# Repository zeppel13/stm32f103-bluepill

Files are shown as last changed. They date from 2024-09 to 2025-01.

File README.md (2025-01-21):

I designed a working simple STM32 devboard to learn how to use KiCad and design my own PCBs

MCU is a genuine STM32F103C8T6. I'll upload an STM32CubeIDE project soon, planning to also put an libopenCM3 project here. For the programming you'll need a standard ST-LINK programmer (A fake one might be working just fine). The PCB exposes a programming interface with SWD, CLK, +3V3 and GND and BOOT0 with Breakers. 

For the programming

    st-flash write firmware.bin 0x08000000 
    
works fine for me

### Goals of the Project
✅ **Learn to use KiCAD**  
✅ Complete all necessary steps to manufacture the board and proceed with prototypes  
✅ Create a Blue Pill-compatible board with a genuine STM32F103 (no clones like GD32, PY32, etc.)  
✅ Provide a base for future MCU PCB design  
✅ Ensure the PCB fits on a breadboard  
✅ Pay special attention to the routing of high-frequency signals: proper differential pairs for USB, a good ground plane, and always low-impedance return paths  
✅ Make it work  

---

### Non-Goals
- Using the newest or best features. STM32F103 might seem a bit outdated compared to newer STM32 offerings. A brand-name Micro USB-B connector will be used — no USB-C.  
- Power optimization (e.g., removing LEDs, using a more efficient voltage supply, or selecting a low-power MCU).  
- Price optimization. The plan is to build a small batch, not large quantities.  

---

### Errata
- The **BOOTP** header in the silkscreen should be **BOOT0**. I confused the technical jargon of Cortex boot modes with DHCP/BOOTP and didn’t realize the mistake until after producing the samples.  
- The SMD switch for BOOT0 was replaced with a pinout that can be configured with jumpers (HI/LOW).  

top
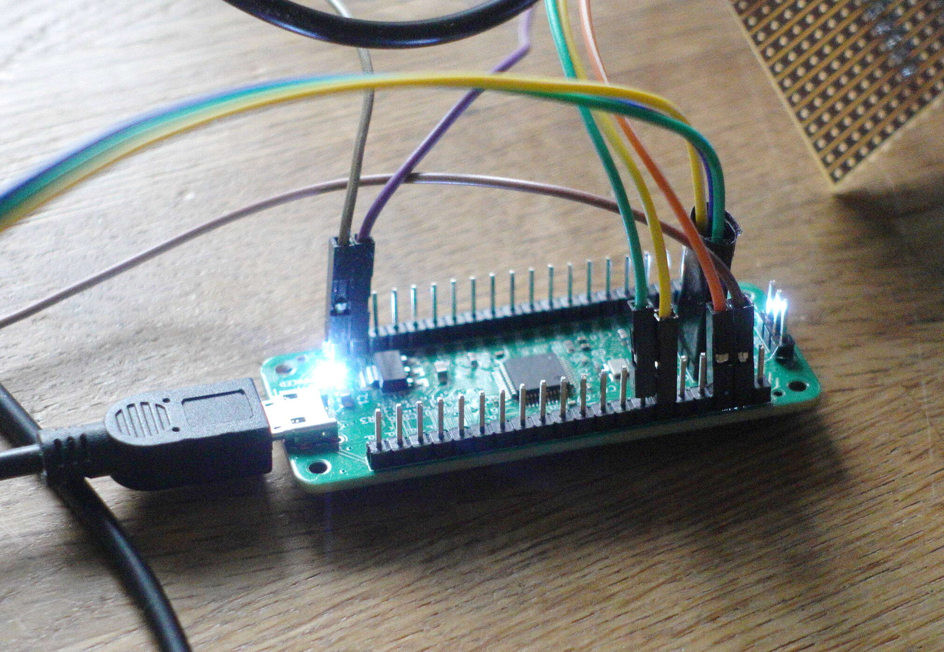
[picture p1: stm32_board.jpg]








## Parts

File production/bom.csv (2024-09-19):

Designator | Footprint | Quantity | Value | LCSC Part #
C1, C2 | 0805 | 2 | 22u
C10, C9 | 0402 | 2 | 1u
C11, C3 | 0603 | 2 | 10u
C12, C13 | 0402 | 2 | 10p
C4, C5, C6, C7 | 0402 | 4 | 100n
C8 | 0402 | 1 | 10n
D1, D2 | 0603 | 2 | RED
FB1 | 0603 | 1 | 120R
H1, H2, H3, H4 | MountingHole_2.2mm_M2 | 4 | MountingHole
J1 | PinHeader_1x04_P2.54mm_Vertical | 1 | Conn_01x04_Male
J2 | USB_Micro-B_Wuerth_629105150521 | 1 | USB_B_Micro
J3 | PinHeader_1x20_P2.54mm_Vertical | 1 | Pinout 1
J4 | PinHeader_1x20_P2.54mm_Vertical | 1 | Pinout 2
R1, R3, R4 | 0402 | 3 | 1k5
R2 | 0402 | 1 | 10k
SW1 | PinHeader_1x03_P2.54mm_Vertical | 1 | Conn_01x03_Male
U1 | SOT-223-3_TabPin2 | 1 | AMS1117-3.3
U2 | LQFP-48_7x7mm_P0.5mm | 1 | STM32F103C8T6
Y1 | Crystal_SMD_3225-4Pin_3.2x2.5mm | 1 | 16MHz

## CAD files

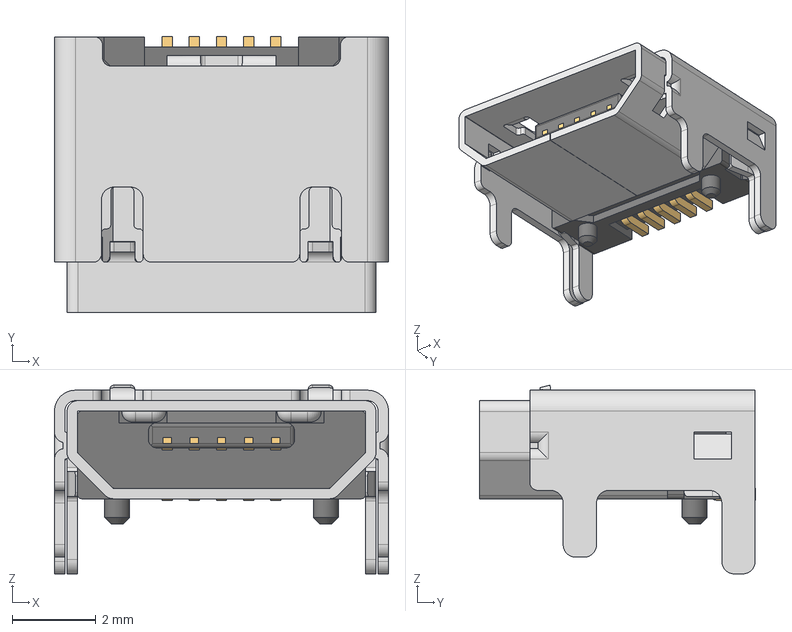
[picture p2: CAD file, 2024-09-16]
629105150521 (rev1).stp
8.00 x 6.60 x 4.52 mm
629105150521_Housing
629105150521_Pin1 x 4
629105150521_Pin2
629105150521_Shielding2
629105150521_Shielding

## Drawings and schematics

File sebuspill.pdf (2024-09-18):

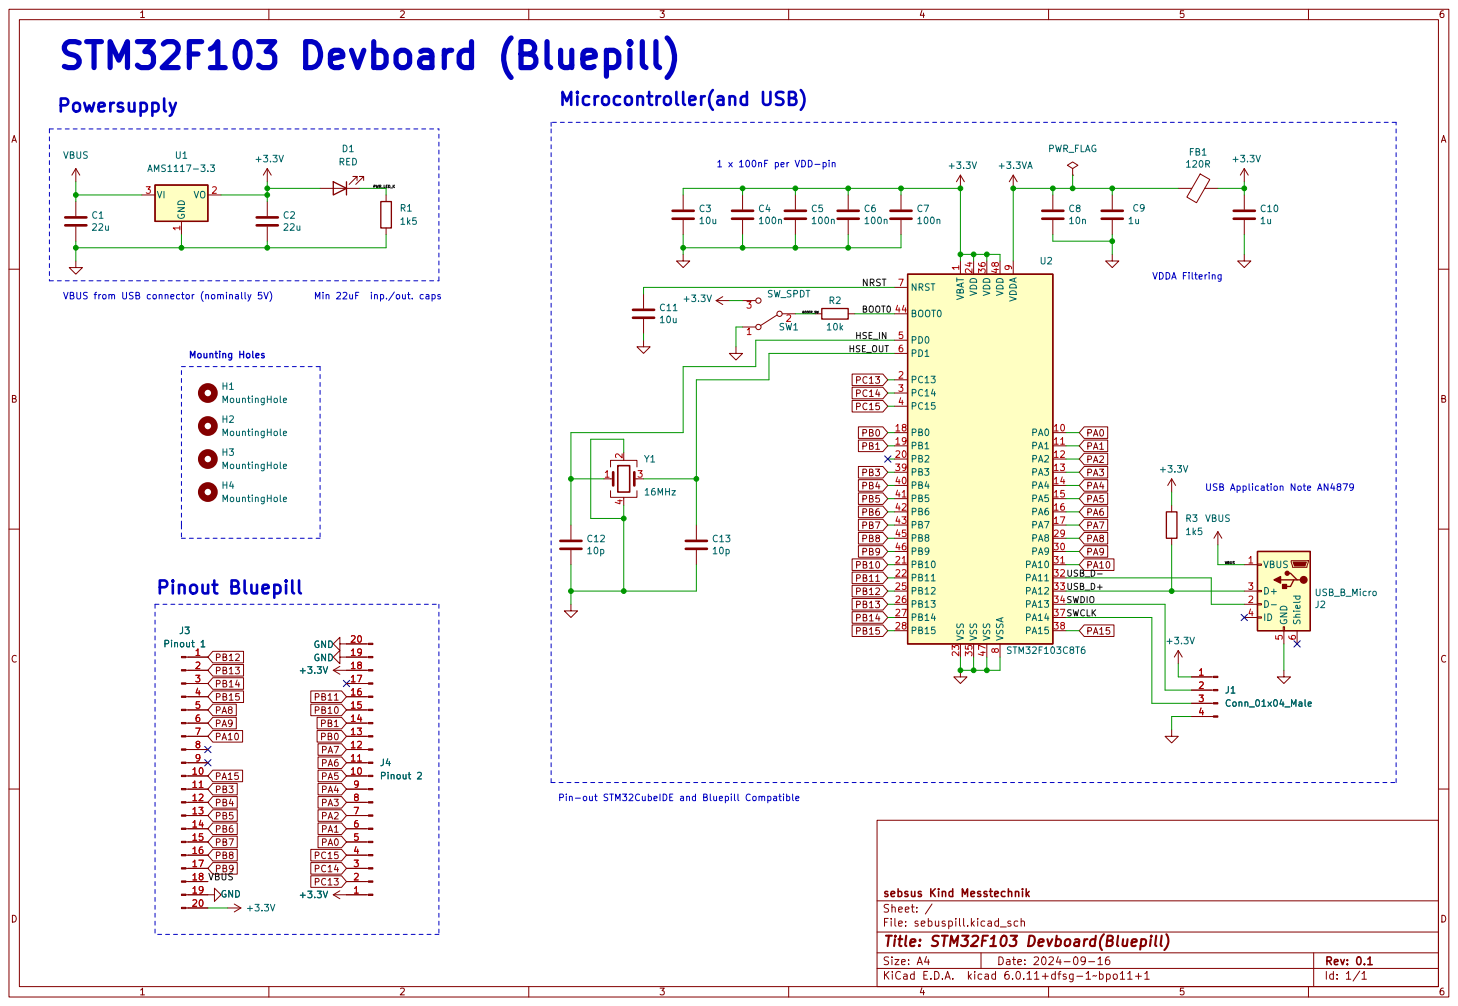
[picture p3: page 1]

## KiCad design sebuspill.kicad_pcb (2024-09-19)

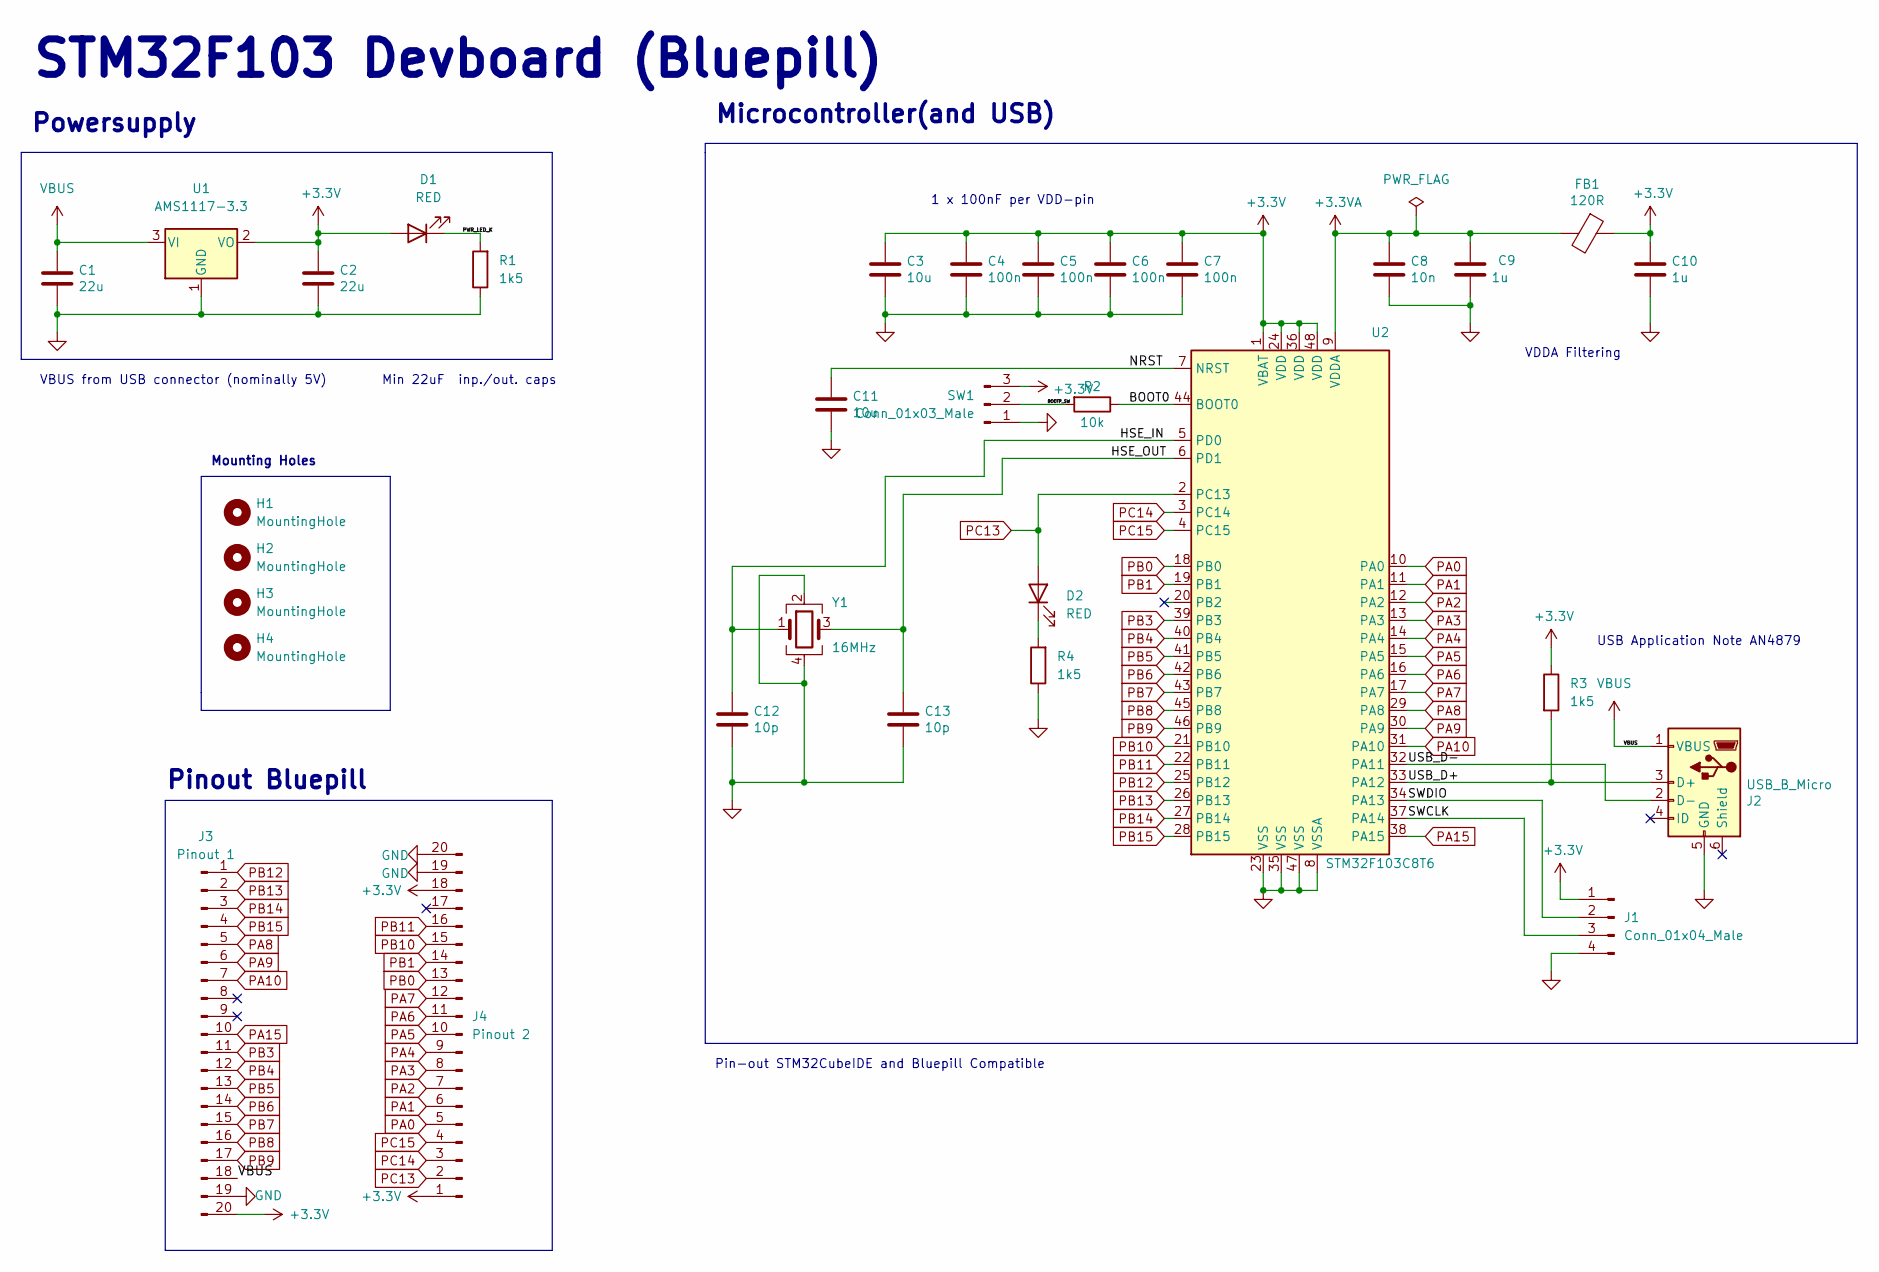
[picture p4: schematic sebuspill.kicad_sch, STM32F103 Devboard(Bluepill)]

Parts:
C1, C2: 22u; C_0805_2012Metric
C3, C11: 10u; C_0603_1608Metric
C4, C5, C6, C7: 100n; C_0402_1005Metric
C8: 10n; C_0402_1005Metric
C9, C10: 1u; C_0402_1005Metric
C12, C13: 10p; C_0402_1005Metric
D1, D2: RED; LED_0603_1608Metric
FB1: 120R; L_0603_1608Metric
H1, H2, H3, H4: MountingHole; MountingHole_2.2mm_M2
J1: Conn_01x04_Male; PinHeader_1x04_P2.54mm_Vertical
J2: USB_B_Micro; USB_Micro-B_Wuerth_629105150521
J3: Pinout 1; PinHeader_1x20_P2.54mm_Vertical
J4: Pinout 2; PinHeader_1x20_P2.54mm_Vertical
R1, R3, R4: 1k5; R_0402_1005Metric
R2: 10k; R_0402_1005Metric
SW1: Conn_01x03_Male
U1: AMS1117-3.3; SOT-223-3_TabPin2
U2: STM32F103C8T6; LQFP-48_7x7mm_P0.5mm
Y1: 16MHz; Crystal_SMD_3225-4Pin_3.2x2.5mm

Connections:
+3.3VA: C8.1, C9.1, FB1.2, U2.9 (VDDA)
+3V3: C2.1, C3.1, C4.1, C5.1, C6.1, C7.1, C10.1, D1.2 (A), FB1.1, J1.1, J3.20, J4.1, J4.18, R3.1, SW1.3, U1.2 (VO), U2.1 (VBAT), U2.24 (VDD), U2.36 (VDD), U2.48 (VDD)
/BOOT0: R2.1, U2.44 (BOOT0)
/BOOTP_SW: R2.2, SW1.2
/HSE_IN: C12.1, U2.5 (PD0), Y1.1
/HSE_OUT: C13.1, U2.6 (PD1), Y1.3
/NRST: C11.1, U2.7 (NRST)
/PWR_LED_K: D1.1 (K), R1.2
/SWCLK: J1.3, U2.37 (PA14)
/SWDIO: J1.2, U2.34 (PA13)
/USB_D+: J2.3 (D+), R3.2, U2.33 (PA12)
/USB_D-: J2.2 (D-), U2.32 (PA11)
GND: C1.2, C2.2, C3.2, C4.2, C5.2, C6.2, C7.2, C8.2, C9.2, C10.2, C11.2, C12.2, C13.2, J1.4, J2.5 (GND), J3.19, J4.19, J4.20, R1.1, R4.1, SW1.1, U1.1 (GND), U2.8 (VSSA), U2.23 (VSS), U2.35 (VSS), U2.47 (VSS), Y1.2, Y1.4
unnamed: D2.1 (K), R4.2
PA0: J4.5, U2.10 (PA0)
PA1: J4.6, U2.11 (PA1)
PA2: J4.7, U2.12 (PA2)
PA3: J4.8, U2.13 (PA3)
PA4: J4.9, U2.14 (PA4)
PA5: J4.10, U2.15 (PA5)
PA6: J4.11, U2.16 (PA6)
PA7: J4.12, U2.17 (PA7)
PA8: J3.5, U2.29 (PA8)
PA9: J3.6, U2.30 (PA9)
PA10: J3.7, U2.31 (PA10)
PA15: J3.10, U2.38 (PA15)
PB0: J4.13, U2.18 (PB0)
PB1: J4.14, U2.19 (PB1)
PB3: J3.11, U2.39 (PB3)
PB4: J3.12, U2.40 (PB4)
PB5: J3.13, U2.41 (PB5)
PB6: J3.14, U2.42 (PB6)
PB7: J3.15, U2.43 (PB7)
PB8: J3.16, U2.45 (PB8)
PB9: J3.17, U2.46 (PB9)
PB10: J4.15, U2.21 (PB10)
PB11: J4.16, U2.22 (PB11)
PB12: J3.1, U2.25 (PB12)
PB13: J3.2, U2.26 (PB13)
PB14: J3.3, U2.27 (PB14)
PB15: J3.4, U2.28 (PB15)
PC13: D2.2 (A), J4.2, U2.2 (PC13)
PC14: J4.3, U2.3 (PC14)
PC15: J4.4, U2.4 (PC15)
VBUS: C1.1, J2.1 (VBUS), J3.18, U1.3 (VI)

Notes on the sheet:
Min 22uF inp./out. caps
Powersupply
1 x 100nF per VDD-pin
Pinout Bluepill
Mounting Holes
USB Application Note AN4879
VBUS from USB connector (nominally 5V)
Microcontroller(and USB)
Pin-out STM32CubeIDE and Bluepill Compatible
STM32F103 Devboard (Bluepill)
VDDA Filtering

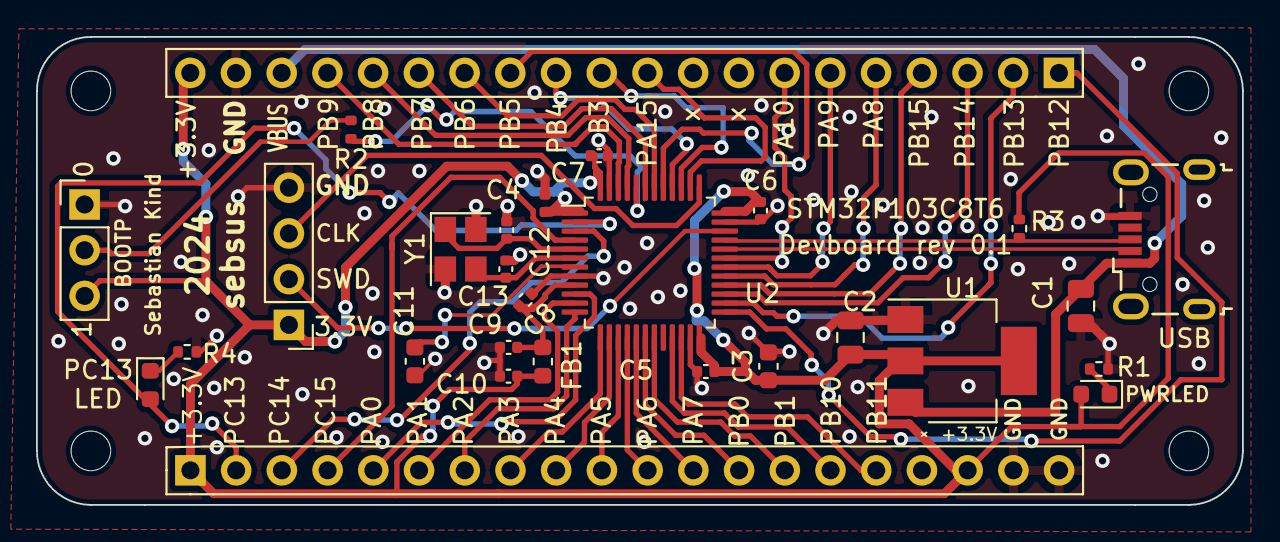
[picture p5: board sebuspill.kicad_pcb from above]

Board: 2 copper layers, 67.0 x 26.0 mm, 32 parts (0 on the bottom side), 45 nets.

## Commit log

2024-09-16 inital commit of bluepill board
    [629105150521 (rev1).stp, sebuspill.kicad_pcb, sebuspill.kicad_sch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]
2024-09-17 added all components, next step routing and outline
    [sebuspill.kicad_pcb, sebuspill.kicad_sch]
2024-09-18 set pinheaders to fit on a bread board
    [sebuspill.kicad_pcb]
2024-09-18 routing halfly done
    [sebuspill.kicad_pcb]
2024-09-18 still routing
    [sebuspill.kicad_pcb]
2024-09-18 trying to route groundplane between all backside wires
    [sebuspill.kicad_pcb]
2024-09-18 finished i think
    [sebuspill.kicad_pcb]
2024-09-19 changed SMD switch to Jumper bc JLCPCB hat no in stock and added User programmable LED to PC13
    [bom.csv, designators.csv, positions.csv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]
2024-09-19 took Jacopops Feedback <3 and rerouted some traces
    [bom.csv, designators.csv, positions.csv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]
2024-09-19 ordered at JLCPCP
    [bom.csv, designators.csv, positions.csv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]
2025-01-21 Added image of the produced prototype
